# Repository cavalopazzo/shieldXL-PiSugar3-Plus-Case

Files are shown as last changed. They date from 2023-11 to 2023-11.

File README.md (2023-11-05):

# shieldXL-PiSugar3-Plus-Case


## **Parts**

(1) Raspberry Pi 3B+ (not tested with 3B or 4)

[(1) Pisugar3 Plus](https://www.amazon.com/dp/B09MJ876FW?psc=1&ref=ppx_yo2ov_dt_b_product_details)

[(4) M2.5x11 male to female standoff](https://www.amazon.com/dp/B09R97DVZY?ref=ppx_yo2ov_dt_b_product_details&th=1)

[(4) M2.5x10 female to female standoff](https://www.amazon.com/gp/product/B09F9GMP4W/ref=ppx_yo_dt_b_search_asin_title?ie=UTF8&psc=1)

(8) M2.5x6 screw

(1) M2.5x10 screw

(1) M2.5x16 screw

(3) M2.5x8 male to female standoff

[(2) M2.5x6 heat set inserts (optional)](https://www.amazon.com/dp/B0B46YBNV4?ref=ppx_yo2ov_dt_b_product_details&th=1)

## **Printing**

Two version of the main case file are included - one meant for heat set inserts on the two leftmost screw holes and one with plain holes meant to be threaded by a screw. 

For the non-heat set version, the original case file has been altered to have 2.25mm diameter holes instead of printing M2.5 threads. Forming/cutting threads with a 
metal M2.5 screw will likely produce more robust threads than FDM printing.

Also included is the power button (required) and some knobs (optional). 

Due to the tight tolerances and depending on many variables, the power button may be too tall or too short. The fusion360 file is provided to 
allow for the quick addition or subtraction of a tenth of a millimeter to the lower, wider section.

There are two knob models, one meant for the right two encoders and one 'lower' one meant for the left encoder which may sit higher than the others.

The case shown here was printed in PLA at a layer height of 0.15mm with a brim. Cura's fuzzy skin option was used to add the texture - thickness of 0.15mm, point distance of 0.4mm.

Fusion360 project files have been included for all models.

## **Assembly**

### **Check power button fitment**

It's best to ensure the power button is the right size before proceding with the full installation.

Install the 11mm and 10mm standoffs on the pisugar. The pisugar may arrive with small orange stickers covering the threads. Remove them.


Put the power button in the case and install the pisugar with battery attached. 



After installing a few of the mounting screws, check that the power button functions well.


### **Install pisugar/pi**

Attach the pisugar to the pi with the 11mm standoffs and add the 10mm standoffs to the pisugar side.



Remove the battery's magnet and attach to the pisugar. The magnet adhesive tape disk may be used later.



Now for the first tricky part - insert the power button into the case and while holding the case upright to keep the power button in place, insert the combo into the case angled as shown 
with the USB and ethernet ports sticking out.


Next tricky part - bend/pull the power button side of the case out while pushing down on the pi/pisugar to get the pi's 3.5mm connector into place without jostling things enough to dislodge the power button.
Make sure the battery wires aren't between the case and the standoff.


Install a couple of the 6mm mounting screws and check that the power button is seated well and functions.



Add some foam on top of the battery (sticking it in place with the magnet's adhesive is a good idea)


### **Install shieldXL board**

If using the case version without heated inserts, now would be a good time to slowly and carefully thread one of the longer M2.5 screws into the left case holes.
Slow, steady, and even downward pressure while turning the driver should form good threads.


Insert the 1/4-inch jacks of the shieldXL board into the case, leaving the rest angled up.


Now for the final tricky part - bend/pull the power button side of the case enough to allow the 3.5mm midi in jack to start lowering into place.



Check that the pi connection header is reasonably well aligned.


Continue pushing down the shieldXL board while making sure the pi connection header is still aligned.



Insert the SD card, power up the pisugar, and make sure that all this bending and pulling hasn't broken anything. Note that the pisugar powers on with a quick tap of the power button followed by holding it down until the blue led illuminates.



### **Final assembly**

Install the 8mm standoffs and 6mm and 10mm screws.


Install the four faceplate screws, starting with the 16mm screw in the lower left corner. 


Install the remaining bottom screws and your favorite knobs and appreciate your newly independent and thicc shieldXL.


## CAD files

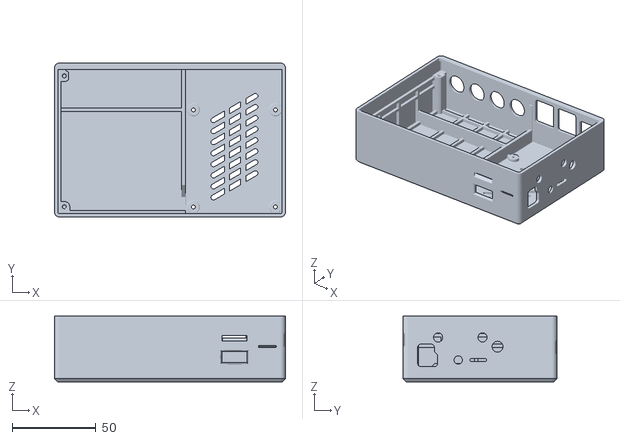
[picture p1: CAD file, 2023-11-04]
shieldXL pisugar3 plus case.stl
138.0 x 92.0 x 39.4

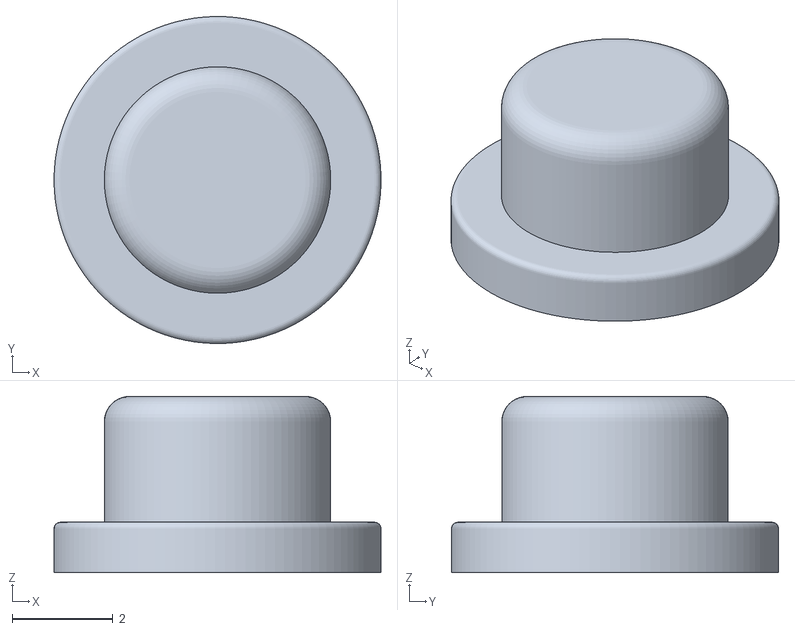
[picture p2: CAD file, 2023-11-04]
shieldXL pisugar3 plus case power switch.stl
6.50 x 6.50 x 3.50

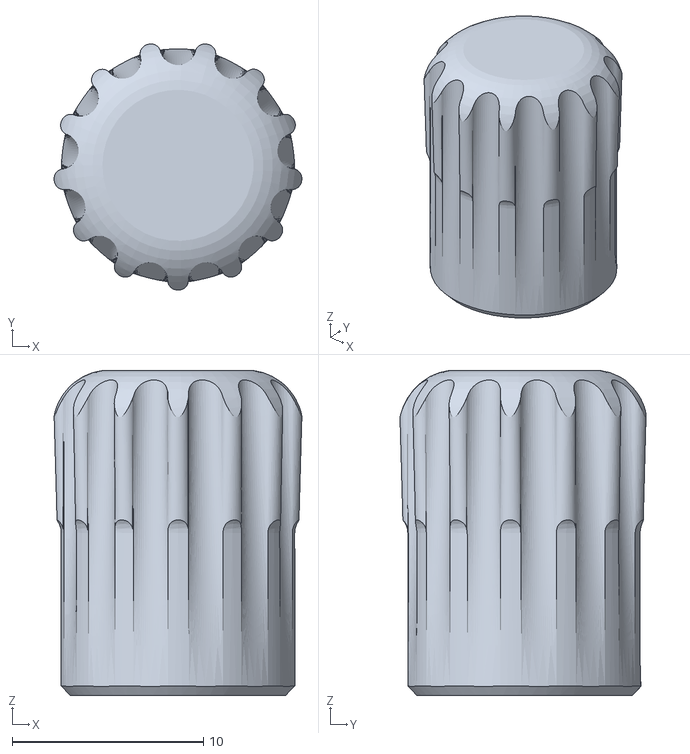
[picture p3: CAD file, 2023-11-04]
shieldXL knob lower.stl
13.0 x 12.9 x 17.0

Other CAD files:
shieldXL pisugar3 plus case heated insert.stl
shieldXL knob.stl
fusion360 files/ShieldXL Batt Case Power Switch.f3d
fusion360 files/shieldXL pisugar3 plus case heated insert.f3d
fusion360 files/shieldXL pisugar3 plus case.f3d
